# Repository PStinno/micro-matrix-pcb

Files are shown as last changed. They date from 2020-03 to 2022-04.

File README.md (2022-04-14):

# µMatrix PCB
Small pcb design (< 1 inch square) with an onboard 5x7 LED matrix, controllable over I2C.



The LED matrix display used is the LTP-305/G from Lite-On Inc. The IS31FL3730 LED matrix driver IC, from ISSI Inc., is used to drive the matrix and provide control over I2C. The I2C address can be selected with solder jumpers on the back of the board from four possible options. It is compatible with power and logic at both 3.3 and 5V.

Also included in this repository is a simple software example for driving the display with an Arduino Uno or similar microcontroller development board. The basic implementation allows for displaying of text on the matrix, either flashed one character at a time or scrolled continuously across the display. Currently the font only supports the capital letters from A-Z and spaces.

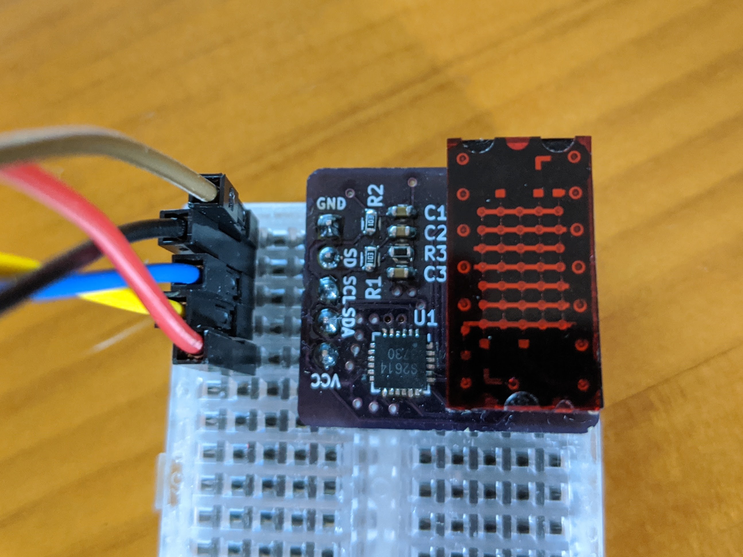
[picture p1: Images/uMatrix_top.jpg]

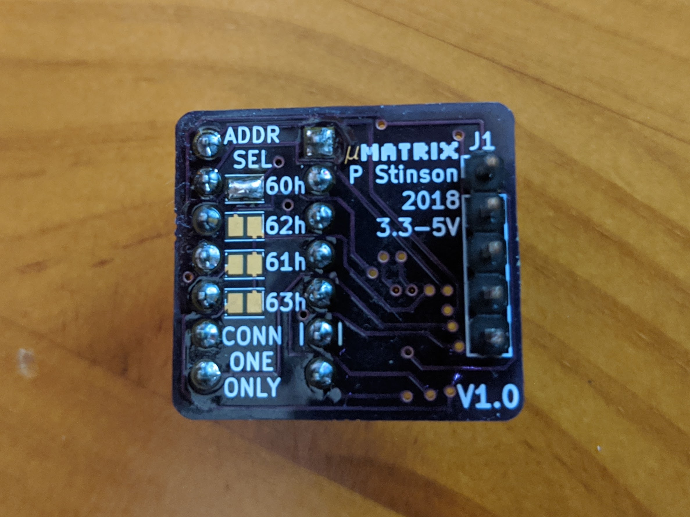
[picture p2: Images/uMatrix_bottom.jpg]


[][cc-by-sa]

[cc-by-sa]: http://creativecommons.org/licenses/by-sa/4.0/
[cc-by-sa-image]: https://licensebuttons.net/l/by-sa/4.0/88x31.png
[cc-by-sa-shield]: https://img.shields.io/badge/License-CC%20BY--SA%204.0-lightgrey.svg

This work is licensed under a [Creative Commons Attribution-ShareAlike 4.0 International License][cc-by-sa].

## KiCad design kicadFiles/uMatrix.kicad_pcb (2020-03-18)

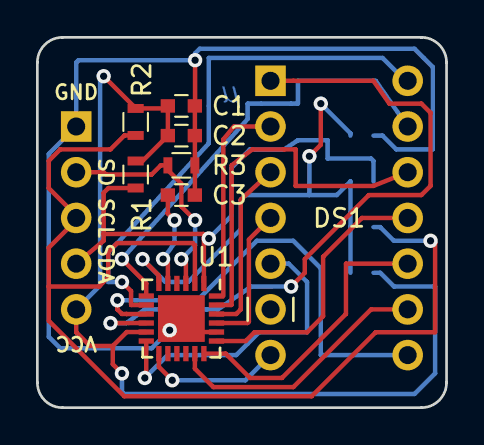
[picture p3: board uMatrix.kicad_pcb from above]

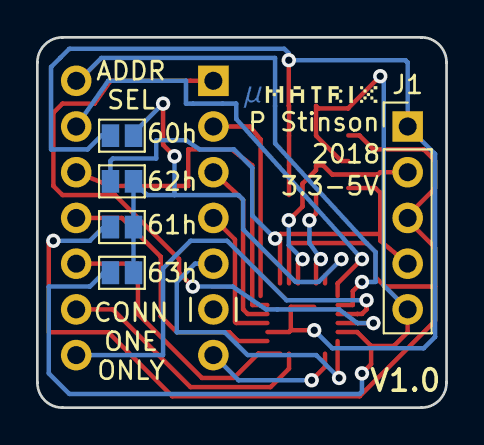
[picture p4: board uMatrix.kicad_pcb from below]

Board: 2 copper layers, 22.7 x 20.6 mm, 13 parts (5 on the bottom side), 20 nets.

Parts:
60h, 61h, 62h, 63h: Jumper_NO_Small; GS2
C1: 1uF; C_0603
C2, C3: 0.1uF; C_0603
DS1: LTP-305
J1: Conn_01x05; Pin_Header_Straight_1x05_Pitch2.54mm
R1, R2: 10K; R_0603
R3: 100K; R_0603
U1: IS31FL3730; QFN-24-1EP_4x4mm_Pitch0.5mm

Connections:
/AD: 60h.1, 61h.1, 62h.1, 63h.1, U1.6
/C1: DS1.5, U1.12
/C2: DS1.1, U1.10
/C3: DS1.8, U1.9
/C4: DS1.14, U1.8
/C5: DS1.13, U1.7
/DP: DS1.7, U1.13
/R1: DS1.2, U1.24
/R2: DS1.12, U1.23
/R3: DS1.3, U1.22
/R4: DS1.4, U1.21
/R5: DS1.11, U1.19
/R6: DS1.10, U1.18
/R7: DS1.9, U1.17
/SCL: 61h.2, J1.3, R2.2, U1.2
/SDA: 62h.2, J1.4, R1.2, U1.1
GND: 60h.2, C1.2, C2.2, C3.2, J1.1, R3.2, U1.20, U1.25
unnamed: C3.1, U1.5
unnamed: J1.2, R3.1, U1.3
VCC: 63h.2, C1.1, C2.1, J1.5, R1.1, R2.1, U1.11

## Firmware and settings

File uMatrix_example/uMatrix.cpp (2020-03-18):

#include "Arduino.h"
#include <Wire.h>
#include <string.h>

#include "uMatrix.h"
#include "uMatrix_font.h"


uMatrix::uMatrix(void) {}

bool uMatrix::init(uint8_t addr, int sd_pin) {
  // Assign instance address and shutdown pin
  i2c_addr = addr;
  shutdown_pin = sd_pin;
  // Configure shutdown pin and enable display
  pinMode(shutdown_pin, OUTPUT);
  digitalWrite(shutdown_pin, HIGH);
  // Start i2c
  Wire.begin();
  // Configure display
  writeReg(i2c_addr, 0x00, 0x00); //Default Config
  writeReg(i2c_addr, 0x0D, 0x09); //10ma Drive Current
  writeReg(i2c_addr, 0x19, 0x80); //Full Brightness
}

void uMatrix::clearMatrix(void) {
  for(int i = 0; i < 7; i++) {
    writeReg(i2c_addr, i+1, 0x00);
  }
  writeReg(i2c_addr, 0x0C, 0xFF);
}

void uMatrix::displayChar(char c) {
  for(int i = 0; i < 7; i++) {
    writeReg(i2c_addr, i+1, font[c - 'A'][i]);
  }
  writeReg(i2c_addr, 0x0C, 0xFF);
}

void uMatrix::flashString(char string[], int stringLength) {
  for(int i = 0; i < stringLength; i++) {
    if(string[i] == ' ') {
      clearMatrix();
    } else {
      displayChar(string[i]);
    }

    delay(400);
    clearMatrix();
    delay(150);
  }

  clearMatrix();
  delay(400);
}

void uMatrix::flashString(char string[]) {
  flashString(string, strlen(string));
}

void uMatrix::scrollString(char string[], int stringLength) {
  int current;
  int next;
  
  for(int i = 0; i < (stringLength - 1); i++) {
    if(string[i] == ' ') {
      current = 26;
    } else {
      current = string[i] - 'A';
    }

    if(string[i + 1] == ' ') {
      next = 26;
    } else {
      next = string[i + 1] - 'A';
    }
    
    for(int j = 0; j < 6; j++) {
      for (int k = 1; k < 8; k++) {
        writeReg(i2c_addr, k, ((font[current][k - 1] << j) | (font[next][k - 1] >> (6 - j))) & 0x1F);
      }
      writeReg(i2c_addr, 0x0C, 0xFF);
      delay(200);
    }
  }

  for (int i = 0; i < 7; i++) {
    writeReg(i2c_addr, i+1, font[next][i]);
  }
  writeReg(i2c_addr, 0x0C, 0xFF);
}

void uMatrix::scrollString(char string[]) {
  scrollString(string, strlen(string));
}

/* ---Private Functions--- */
void uMatrix::writeReg(uint8_t addr, uint8_t reg, uint8_t data) {
  Wire.beginTransmission(addr);
  Wire.write(reg);
  Wire.write(data);
  Wire.endTransmission();
}

uint8_t uMatrix::readReg(uint8_t addr, uint8_t reg) {
  uint8_t retVal = 0xFF;
  Wire.beginTransmission(addr);
  Wire.write(reg);
  Wire.endTransmission(false);
  Wire.requestFrom(addr, (uint8_t) 1);
  if (Wire.available() >= 1) {
   retVal = Wire.read();
  }
  return retVal;
}

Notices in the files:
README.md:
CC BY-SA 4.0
